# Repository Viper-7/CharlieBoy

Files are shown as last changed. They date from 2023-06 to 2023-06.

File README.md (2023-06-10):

# CharlieBoy

A hand-held gaming console / Arduino experimenters kit.

A1CyZcg

Just yesterday I learned I have a nephew who is turning 11 next week, with interests in computers, gaming, and art. This was my 24 hour project to make a gift for him, as a toy and hopefully a gateway into the wide world of electronics.

As it comes it's a Tetris game, simple but surprisingly addictive, I caught myself getting carried away playing it more than a few times while testing 😁 The code for it is in this repository. The LCD is an older ILI9328 shield I had lying around, and I couldn't find many finished game projects for it, so I ported this one from https://github.com/vilaca/Handheld-Color-Console/tree/master/ArduinoTetris



However the real trick is the fact that the unit itself is only held together by the pins on the shield - you can literally just rip the thing apart and start hacking. Once the cover is off there's an Arduino Uno, fully available and ready for breadboarding, with a lithium battery and charger hidden beneath it, and a touchscreen, joystick with button, and power switch for user interface.

C0damcI

It's intended to be a platform to start learning electronics and microcontroller development. It's fully customizable, the game on it can be changed or replaced, they can add buttons, dials, lights, etc to it, use the Touchscreen and SD card reader to show photos or art, etc, etc.

The Arduino and Joystick are bolted down, with brass inserts melted into the 3d print. The switch is held in with a screw on collar, and the LCD (both the shield on the inside and the display on the outside) are attached with VHB tape.



Hiding under the Arduino is a TP4056 + DW01 lithium charger + protection module, and a small 500mAh 1S LiPo battery, along with a diode and 2A PTC fuse so any mishaps are a little less dramatic. The joystick is wired to A6 and A7, which are not available on most Arduino Uno boards, but were broken out on this board so I used those to avoid occupying any "regular" pins. With the screen removed, only the switch inside the joystick shares with a regular arduino pin, A5.



Total parts cost was under $20, although shipping may vary. I've included the OpenSCAD files for the chassis, and a list of everything else used in aliexpress links down below



Complete Parts List:

* LCD Module: https://s.click.aliexpress.com/e/_DnsErhJ
* Arduino Uno with A6+A7: https://s.click.aliexpress.com/e/_DmORDdP
* TP4056+DW01: https://s.click.aliexpress.com/e/_DeaHOff
* Joystick Module: https://s.click.aliexpress.com/e/_Dd41Vq1
* Switch + Cover: https://s.click.aliexpress.com/e/_DmSk5vR
* M2 Threaded Inserts: https://s.click.aliexpress.com/e/_DDOrytL
* M2 Bolts: https://s.click.aliexpress.com/e/_DEwoBIp
* 500mAh Battery: https://s.click.aliexpress.com/e/_DCwWl85

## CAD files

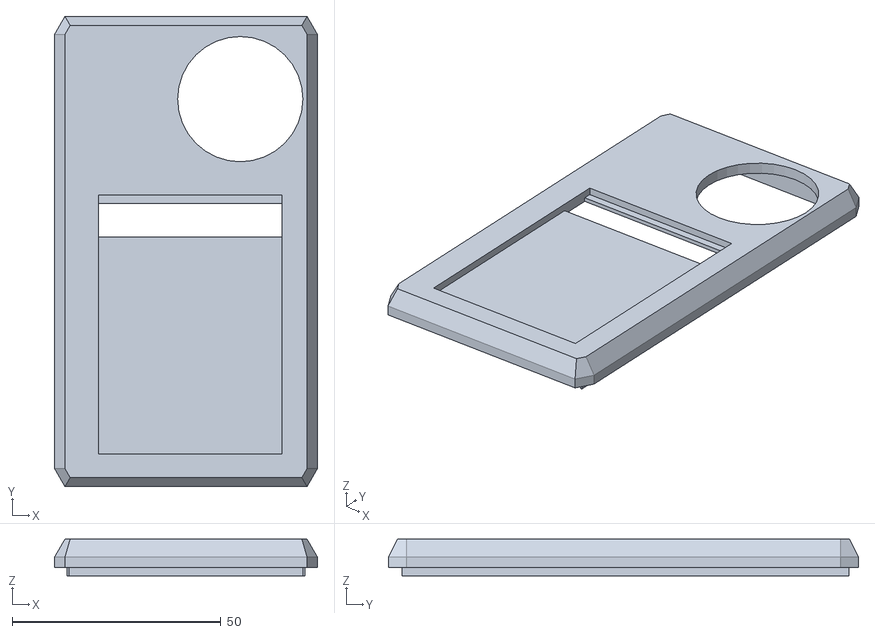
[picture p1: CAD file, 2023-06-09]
CharlieBoy_Lid.stl
63.0 x 112.7 x 8.83

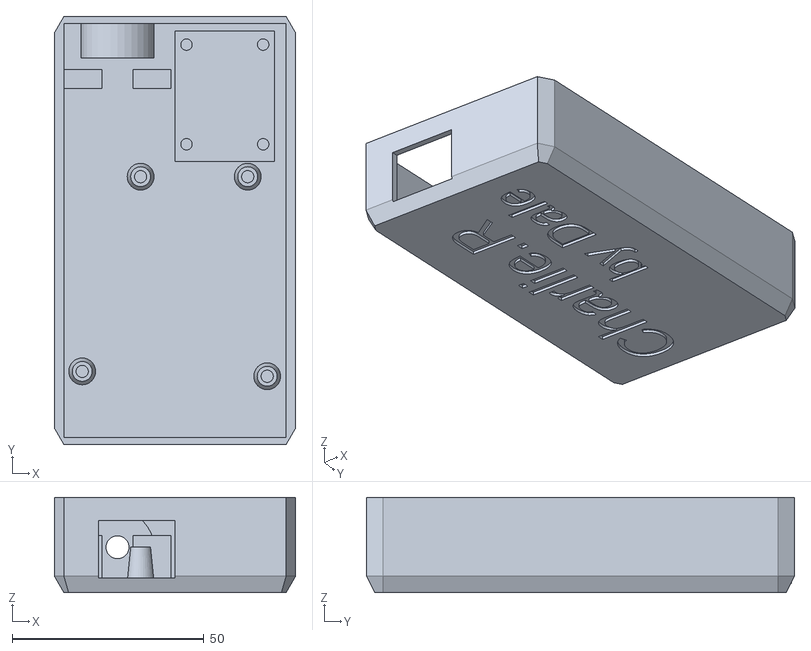
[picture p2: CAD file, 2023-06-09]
CharlieBoy_base.stl
63.0 x 111.7 x 24.8

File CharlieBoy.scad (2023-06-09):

$fn=32;

translate([60,0,25]) rotate([180,0,180]) lid();
//base();

module base() {

 difference() {
    $rad = 5;
    
    color("orange") minkowski() {
        translate([1+$rad/2,1+$rad/2,$rad/2]) cube([58-$rad, 108-$rad,30]);
        sphere($rad, $fn=6);
    }
    translate([1,1,1]) cube([58,108,35]);
    translate([-5,-5,23]) cube([70,150,50]);
    //translate([10,-5,10]) cube([45,10,15]);
    translate([10,-5,2]) cube([20,10,15]);
    translate([15,103,10]) rotate([0,90,90]) cylinder(20, 7.5, 7.5);
    color("gray") rotate([0,180,0]) translate([-28,103,1]) rotate([0,0,270]) linear_extrude(5) text("Charlie.R", size=15);
    color("gray") rotate([0,180,0]) translate([-46,65,1]) rotate([0,0,270]) linear_extrude(5) text("by Dale", size=12);
}

translate([3.25,3,0]) union() {
    //translate([0,0,10]) arduino();
    standoffs();
}

translate([1,92,0]) cube([10,5,13]);
translate([19,92,0]) cube([10,5,13]);

difference() {
    translate([15,100,10]) rotate([0,90,90]) cylinder(10, 9.5, 9.5);
    
    translate([15,103,10]) rotate([0,90,90]) cylinder(20, 7.5, 7.5);
    translate([15,90,10]) rotate([0,90,90]) cylinder(50, 3, 3);
}

//translate([30,75,20])  color("darkgray",1) joystick();
translate([30,73,1]) difference() {
    cube([26,34,12]);
    translate([0,0,2]) joystickHoles();
}
}

module lid() {
color("gray") difference() {
    $rad = 5;
    
    minkowski() {
        translate([1+$rad/2,+$rad/2,$rad/2]) cube([58-$rad, 109-$rad,30]);
        sphere($rad, $fn=6);
    }
    translate([1,0,1]) cube([58,108,35]);
    translate([-5,-5,5]) cube([70,150,50]);
    translate([7,58,-7]) cube([44,8,30]);
    translate([7,6,-5]) cube([44,62,5]);
    translate([17,89,-10]) cylinder(18,15,15);
}

//translate([9,6,-5]) color("white") cube([42,60,5]);
//translate([10,7,-5.1]) color("black") cube([40,58,2]);

difference() {
    union() {
        translate([1,2,1]) cube([58,107,4]);
        translate([1.5,1.5,1]) cube([57,107,6]);
    }
    translate([2,0,1]) cube([56,108,16]);
    translate([7,58,-7]) cube([44,8,30]);
    translate([17,89,-10]) cylinder(18,15,15);
}
}

module joystickHoles() {
    translate([3,4.5,0]) union() {
        translate([0,0,0]) cylinder(50, 1.5, 1.5);
        translate([20,0,0]) cylinder(50, 1.5, 1.5);
        translate([0,26,0]) cylinder(50, 1.5, 1.5);
        translate([20,26,0]) cylinder(50, 1.5, 1.5);
    }
}
    
module joystick() {
    difference() {
        cube([26,34,6]);
        joystickHoles();
    }
    translate([13,17,6]) cylinder(16,6,6);
    translate([13,17,14]) intersection() { sphere(12); cylinder(10,13,13); }
}


// Arduino connectors library
//
// Copyright (c) 2013 Kelly Egan
//
// The MIT License (MIT)
//
// Permission is hereby granted, free of charge, to any person obtaining a copy of this software 
// and associated documentation files (the "Software"), to deal in the Software without restriction, 
// including without limitation the rights to use, copy, modify, merge, publish, distribute, sublicense,
// and/or sell copies of the Software, and to permit persons to whom the Software is furnished to do 
// so, subject to the following conditions:
//
// The above copyright notice and this permission notice shall be included in all copies or substantial
// portions of the Software.
//
// THE SOFTWARE IS PROVIDED "AS IS", WITHOUT WARRANTY OF ANY KIND, EXPRESS OR IMPLIED, INCLUDING BUT 
// NOT LIMITED TO THE WARRANTIES OF MERCHANTABILITY, FITNESS FOR A PARTICULAR PURPOSE AND NONINFRINGEMENT. 
// IN NO EVENT SHALL THE AUTHORS OR COPYRIGHT HOLDERS BE LIABLE FOR ANY CLAIM, DAMAGES OR OTHER LIABILITY,
// WHETHER IN AN ACTION OF CONTRACT, TORT OR OTHERWISE, ARISING FROM, OUT OF OR IN CONNECTION WITH THE 
// SOFTWARE OR THE USE OR OTHER DEALINGS IN THE SOFTWARE.
//

use <pin_connectors/pins.scad>

//Constructs a roughed out arduino board
//Current only USB, power and headers
module arduino(boardType = UNO) {
  //The PCB with holes
  difference() {
    color("SteelBlue") 
      boardShape( boardType );
    translate([0,0,-pcbHeight * 0.5]) holePlacement(boardType = boardType)
      color("SteelBlue") cylinder(r = mountingHoleRadius, h = pcbHeight * 2, $fn=32);
  }
  //Add all components to board
  components( boardType = boardType, component = ALL );
}

//Creates a bumper style enclosure that fits tightly around the edge of the PCB.
module bumper( boardType = UNO, mountingHoles = false ) {
  bumperBaseHeight = 2;
  bumperHeight = bumperBaseHeight + pcbHeight + 0.5;
  dimensions = boardDimensions(boardType);

  difference() {
    union() {
      //Outer rim of bumper
      difference() {
        boardShape(boardType = boardType, offset=1.4, height = bumperHeight);
        translate([0,0,-0.1])
          boardShape(boardType = boardType, height = bumperHeight + 0.2);
      }

      //Base of bumper  
      difference() {
        boardShape(boardType = boardType, offset=1, height = bumperBaseHeight);
        translate([0,0, -0.1])
          boardShape(boardType = boardType, offset=-2, height = bumperHeight + 0.2);
      }

      //Board mounting holes
      holePlacement(boardType=boardType)
        cylinder(r = mountingHoleRadius + 1.5, h = bumperBaseHeight, $fn = 32);

      //Bumper mounting holes (exterior)
      if( mountingHoles ) {
        difference() {  
          hull() {
            translate([-6, (dimensions[1] - 6) / 2, 0])
              cylinder( r = 6, h = pcbHeight + 2, $fn = 32 );
            translate([ -0.5, dimensions[1] / 2 - 9, 0])
              cube([0.5, 12, bumperHeight]);
          }
          translate([-6, (dimensions[1] - 6) / 2, 0])
            mountingHole(holeDepth = bumperHeight);
        }
        difference() {  
          hull() {
            translate([dimensions[0] + 6, (dimensions[1] - 6) / 2,0])
              cylinder( r = 6, h = pcbHeight + 2, $fn = 32 );
            translate([ dimensions[0], dimensions[1] / 2 - 9, 0]) 
              cube([0.5, 12, bumperHeight]);
          }
          translate([dimensions[0] + 6, (dimensions[1] - 6) / 2,0])
            mountingHole(holeDepth = bumperHeight);
        }
      }
    }
    translate([0,0,-0.5])
    holePlacement(boardType=boardType)
      cylinder(r = mountingHoleRadius, h = bumperHeight, $fn = 32);  
    translate([0, 0, bumperBaseHeight]) {
      components(boardType = boardType, component = ALL, offset = 1);
    }
    translate([4,(dimensions[1] - dimensions[1] * 0.4)/2,-1])
      cube([dimensions[0] -8,dimensions[1] * 0.4,bumperBaseHeight + 2]);
  }
}

//Setting for enclosure mounting holes (Not Arduino mounting)
NOMOUNTINGHOLES = 0;
INTERIORMOUNTINGHOLES = 1;
EXTERIORMOUNTINGHOLES = 2;

//Create a board enclosure
module enclosure(boardType = UNO, wall = 3, offset = 3, heightExtension = 10, cornerRadius = 3, mountType = TAPHOLE) {
  standOffHeight = 5;

  dimensions = boardDimensions(boardType);
  boardDim = boardDimensions(boardType);
  pcbDim = pcbDimensions(boardType);

  enclosureWidth = pcbDim[0] + (wall + offset) * 2;
  enclosureDepth = pcbDim[1] + (wall + offset) * 2;
  enclosureHeight = boardDim[2] + wall + standOffHeight + heightExtension;

  union() {
    difference() {
      //Main box shape
      boundingBox(boardType = boardType, height = enclosureHeight, offset = wall + offset, include=PCB, cornerRadius = wall);
  
      translate([ 0, 0, wall]) {
        //Interior of box
        boundingBox(boardType = boardType, height = enclosureHeight, offset = offset, include=PCB, cornerRadius = wall);
  
        //Punch outs for USB and POWER
        translate([0, 0, standOffHeight]) {
          components(boardType = boardType, offset = 1, extension = wall + offset + 10);
        }
      }
      
      //Holes for lid clips
      translate([0, enclosureDepth * 0.75 - (offset + wall), enclosureHeight]) {
        translate([-offset, 0, 0])
          rotate([0, 180, 90]) clipHole(clipHeight = 10, holeDepth = wall + 0.2);
        translate([offset + boardDim[0], 0, 0])
          rotate([0, 180, 270]) clipHole(clipHeight = 10, holeDepth = wall + 0.2);
      }
    
      translate([0, enclosureDepth * 0.25 - (offset + wall), enclosureHeight]) {
        translate([-offset, 0, 0])
          rotate([0, 180, 90]) clipHole(clipHeight = 10, holeDepth = wall + 0.2);
        translate([offset + dimensions[0], 0, 0])
          rotate([0, 180, 270]) clipHole(clipHeight = 10, holeDepth = wall + 0.2);
      }   
    }
    translate([0, 0, wall]) {
      standoffs(boardType = boardType, height = standOffHeight, mountType = mountType);
    }
  }
}

//Create a snap on lid for enclosure
module enclosureLid( boardType = UNO, wall = 3, offset = 3, cornerRadius = 3, ventHoles = false) {
  dimensions = boardDimensions(boardType);
  boardDim = boardDimensions(boardType);
  pcbDim = pcbDimensions(boardType);

  enclosureWidth = pcbDim[0] + (wall + offset) * 2;
  enclosureDepth = pcbDim[1] + (wall + offset) * 2;
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

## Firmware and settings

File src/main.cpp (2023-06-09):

#include <Arduino.h>

// Simple Drawing Script for AZ-Delivery TFT Touch 240x320 Shield
// Tony Goodhew 30 Sept 2020
// Modified from Adafruit examples for a similar shield
// Tutorial45.com
// Adafruit GFX Libraries
#include <Adafruit_GFX.h>
#include <Adafruit_TFTLCD.h>
#include <Fonts/FreeSans18pt7b.h>
#include <Fonts/FreeMono9pt7b.h>

#include "joystick.cpp"
#include "beeping.cpp"
//#include "sequencer.cpp"


#define LCD_CS A3     // Chip Select goes to Analog 3
#define LCD_CD A2     // Command/Data goes to Analog 2
#define LCD_WR A1     // LCD Write goes to Analog 1
#define LCD_RD A0     // LCD Read goes to Analog 0
#define LCD_RESET A4  // Can alternately just connect to Arduino's reset pin

// 16-bit colour values:
#define BLACK 0xFFFF
#define BLUE 0x001F
#define RED 0xF800
#define GREEN 0x07E0
#define CYAN 0x07FF
#define MAGENTA 0xF81F
#define YELLOW 0xFFE0
#define ORANGE 0xF87F
#define WHITE 0x0000
#define GRAY2 0xF7EF
unsigned int c[] = {BLACK,RED,GREEN,BLUE,CYAN,MAGENTA,YELLOW,WHITE};
int cc = c[1];

// Create the TFT (Graphics) object - named pins
Adafruit_TFTLCD tft(LCD_CS, LCD_CD, LCD_WR, LCD_RD, LCD_RESET);



#define LCD_WIDTH             319
#define LCD_HEIGHT            239

#define MIN(X, Y)             (((X) < (Y)) ? (X) : (Y))

#define BOARD_WIDTH           11
#define BOARD_HEIGHT          20

#define BLOCK_SIZE            MIN( (LCD_WIDTH-1) / BOARD_WIDTH, (LCD_HEIGHT-1) / BOARD_HEIGHT )

#define BOARD_LEFT            118//(LCD_WIDTH - BOARD_WIDTH * BLOCK_SIZE)/3*4
#define BOARD_RIGHT           (BOARD_LEFT + BLOCK_SIZE * BOARD_WIDTH)
#define BOARD_TOP             80//(LCD_HEIGHT - BOARD_HEIGHT * BLOCK_SIZE) / 2
#define BOARD_BOTTOM          (BOARD_TOP + BOARD_HEIGHT * BLOCK_SIZE)

#define PIT_COLOR             GREEN
#define BG_COLOR              BLACK

#define DROP_WAIT_INIT        1100

#define INPUT_WAIT_ROT        300
#define INPUT_WAIT_MOVE       150

#define INPUT_WAIT_NEW_SHAPE  400

// used to clear the position from the screen
typedef struct Backup {
  byte x, y, rot;
};


class Tetris
{
  // shapes definitions
  
  byte l_shape[4][4][2] {
    {{0, 0}, {0, 1}, {0, 2}, {1, 2}},
    {{0, 1}, {1, 1}, {2, 0}, {2, 1}},
    {{0, 0}, {1, 0}, {1, 1}, {1, 2}},
    {{0, 0}, {0, 1}, {1, 0}, {2, 0}},
  };

  byte j_shape[4][4][2] {
    {{1, 0}, {1, 1}, {0, 2}, {1, 2}},
    {{0, 0}, {1, 0}, {2, 0}, {2, 1}},
    {{0, 0}, {1, 0}, {0, 1}, {0, 2}},
    {{0, 0}, {0, 1}, {1, 1}, {2, 1}},
  };

  byte o_shape[1][4][2] {
    { {0, 0}, {0, 1}, {1, 0}, {1, 1}}
  };

  byte s_shape[2][4][2] {
    {{0, 1}, {1, 0}, {1, 1}, {2, 0}},
    {{0, 0}, {0, 1}, {1, 1}, {1, 2}}
  };

  byte z_shape[2][4][2] {
    {{0, 0}, {1, 0}, {1, 1}, {2, 1}},
    {{1, 0}, {0, 1}, {1, 1}, {0, 2}}
  };

  byte t_shape[4][4][2] {
    {{0, 0}, {1, 0}, {2, 0}, {1, 1}},
    {{0, 0}, {0, 1}, {1, 1}, {0, 2}},
    {{1, 0}, {0, 1}, {1, 1}, {2, 1}},
    {{1, 0}, {0, 1}, {1, 1}, {1, 2}}
  };

  byte i_shape[2][4][2] {
    {{0, 0}, {1, 0}, {2, 0}, {3, 0}},
    {{0, 0}, {0, 1}, {0, 2}, {0, 3}}
  };

  // All game shapes and their colors

  byte *all_shapes[7] = {l_shape[0][0], j_shape[0][0], o_shape[0][0], s_shape[0][0], z_shape[0][0], t_shape[0][0], i_shape[0][0]};

  unsigned int colors[7] = {ORANGE, BLUE, YELLOW, GREEN, RED, MAGENTA, CYAN};


  // how many rotated variations each shape has
  
  byte shapes[7] = {4, 4, 1, 2, 2, 4, 2};


  // game progress
  
  int lines, level;

  // current shapes
  
  byte current;
  
  // tetris guidelines have all 7 shapes
  // selected in sequence to avoid
  // long runs without a shape
  
  byte next[7];
  byte next_c;

  unsigned long lastInput, lastDrop;

  byte board[BOARD_HEIGHT][BOARD_WIDTH];

  byte x, y, rot;
  Backup old;

  boolean newShape;

  int dropWait;

  public:
  Tetris() : newShape(true), lines(0)
  {
  }

  void run()
  {
    randomSeed(analogRead(2));

    for ( int i = 0; i < BOARD_WIDTH; i++ )
    {
      for ( int j = 0; j < BOARD_HEIGHT; j++)
      {
        board[j][i] = 0;
      }
    }

    //next shape
    
    randomizer();

    // initialize game logic
    
    lastInput = 0;
    lastDrop = 0;
    dropWait = DROP_WAIT_INIT;
    level = 1;

    // draw background
    int c = LCD_WIDTH / 28;
    for (int i = 0; i<=28;i++)
    {
      tft.fillRect(0, i*c, LCD_HEIGHT, c, tft.color565(min((i+5)*12,255),min((i+15)*8,255),i*7));
    }

    tft.fillRect(BOARD_LEFT, BOARD_TOP, BOARD_RIGHT-BOARD_LEFT-1, BOARD_BOTTOM-BOARD_TOP, BG_COLOR);

    // draw board left limit
    
    tft.drawLine (
      BOARD_LEFT - 1,
      BOARD_TOP-1,
      BOARD_RIGHT,
      BOARD_TOP-1,
      PIT_COLOR);

    // draw board left limit
    
    tft.drawLine (
      BOARD_LEFT - 1,
      BOARD_TOP,
      BOARD_LEFT - 1,
      BOARD_BOTTOM,
      PIT_COLOR);

    // draw board right limit
    
    tft.drawLine (
      BOARD_RIGHT,
      BOARD_TOP,
      BOARD_RIGHT,
      BOARD_BOTTOM,
      PIT_COLOR);

    // draw board bottom limit
    
    tft.drawLine (
      BOARD_LEFT - 1,
      BOARD_BOTTOM,
      BOARD_RIGHT + 1,
      BOARD_BOTTOM,
      PIT_COLOR);

    for ( int i = BOARD_LEFT + BLOCK_SIZE - 1; i < BOARD_RIGHT; i += BLOCK_SIZE)
    {
      tft.drawLine (
        i,
        BOARD_TOP,
        i,
        BOARD_BOTTOM - 1,
        GRAY2);
    }

    for ( int i = BOARD_TOP + BLOCK_SIZE - 1; i < BOARD_BOTTOM; i += BLOCK_SIZE)
    {
      tft.drawLine (
        BOARD_LEFT,
        i,
        BOARD_RIGHT - 1,
        i,
        GRAY2);
    }

    scoreBoard();

    do {

      // get clock
      const unsigned long now = millis();

      // display new shape
      if ( newShape )
      {
        Joystick::waitForRelease(INPUT_WAIT_NEW_SHAPE);
        newShape = false;

        // a new shape enters the game
        chooseNewShape();

        // draw next box
        tft.fillRect(30, 100, BLOCK_SIZE * 6, BLOCK_SIZE * 5, BLACK);
        tft.drawRect(29, 99, BLOCK_SIZE * 6 + 1, BLOCK_SIZE * 5 + 1, WHITE);

        byte *shape = all_shapes[next[next_c]];
        for ( int i = 0; i < 4; i++ )
        {
          byte *block = shape + i * 2;
          tft.fillRoundRect(
            30 + BLOCK_SIZE + block[0]*BLOCK_SIZE,
            100 + BLOCK_SIZE + block[1]*BLOCK_SIZE,
            BLOCK_SIZE - 2,
            BLOCK_SIZE - 2 ,
            1,
            colors[next[next_c]]);
        }

        // check if new shape is placed over other shape(s)
        // on the board
        if ( touches(0, 0, 0 ))
        {
          // draw shape to screen
          draw();
          return;
        }

        // draw shape to screen
        draw();
      }
      else
      {
        // check if enough time has passed since last time the shape
        // was moved down the board
        if ( now - lastDrop > dropWait || Joystick::getY() > Joystick::NEUTRAL)
        {
          // update clock
          lastDrop = now;
          moveDown();
          delay(10);
        }
      }

      if (!newShape)
      {
        userInput(now);
      }

    } while (true);
  }

  private:

  void chooseNewShape()
  {
    current = next[next_c];

    next_c++;
    
    if ( next_c == 7 )
    {
      randomizer();
    }

    // new shape must be positioned at the middle of
    // the top of the board
    // with zero rotation
    
    rot = 0;
    y = 0;
    x = BOARD_WIDTH / 2;

    old.rot = rot;
    old.y = y;
    old.x = x;
  }

  void userInput(unsigned long now)
  {
    unsigned long waited = now - lastInput;

    int jx = Joystick::getX();    

    int move = INPUT_WAIT_MOVE / jx;

    if ( jx < Joystick::NEUTRAL && waited > -move)
    {
      if  (x > 0 && !touches(-1, 0, 0))
      {
        x--;
        lastInput = now;
        draw();
      }
    }
    else if ( jx > Joystick::NEUTRAL && waited > move )
    {
      if ( x < BOARD_WIDTH && !touches(1, 0, 0))
      {
        x++;
        lastInput = now;
        draw();
      }
    }
    
    if ( Joystick::fire() )
    {
      while ( !touches(0, 1, 0 ))
      {
        y++;
      }
      lastInput = now;
      draw();
    }

    int my = Joystick::getY();
    if (( my == -Joystick::HARD && waited > INPUT_WAIT_ROT ) || ( my == -Joystick::HARDER && waited > INPUT_WAIT_ROT / 2 ))
    {
      if (Joystick::getY() < 0 && !touches(0, 0, 1))
      {
        rot++;
        rot %= shapes[current];
        lastInput = now;
        draw();
      }
    }
  }

  void moveDown()
  {
    // prepare to move down
    // check if board is clear bellow
    
    if ( touches(0, 1, 0 ))
    {
      // moving down touches another shape
      newShape = true;

      // this shape wont move again
      // add it to the board
      
      byte *shape = all_shapes[current];
      for ( int i = 0; i < 4; i++ )
      {
        byte *block = (shape + (rot * 4 + i) * 2);
        board[block[1] + y][block[0] + x] = current + 1;
      }

      // check if lines were made
      
      score();
      Beeping::beep(1500, 25);
    }
    else
    {
      // move shape down
      y += 1;
      draw();
    }
  }

  void draw()
  {
    byte *shape = all_shapes[current];
    for ( int i = 0; i < 4; i++ )
    {
      byte *block = (shape + (rot * 4 + i) * 2);

      tft.fillRoundRect(
        BOARD_LEFT + block[0]*BLOCK_SIZE + BLOCK_SIZE * x,
        BOARD_TOP + block[1]*BLOCK_SIZE + BLOCK_SIZE * y,
        BLOCK_SIZE - 2,
        BLOCK_SIZE - 2 ,
        1,
        colors[current]);

      board[block[1] + y][block[0] + x] = 255;
    }

    // erase old
    for ( int i = 0; i < 4; i++ )
    {
      byte *block = (shape + (old.rot * 4 + i) * 2);

      if ( board[block[1] + old.y][block[0] + old.x] == 255 )
      continue;

      tft.fillRect(
        BOARD_LEFT + block[0]*BLOCK_SIZE + BLOCK_SIZE * old.x,
        BOARD_TOP + block[1]*BLOCK_SIZE + BLOCK_SIZE * old.y,
        BLOCK_SIZE - 2,
        BLOCK_SIZE - 2 ,
        BG_COLOR);
    }

    for ( int i = 0; i < 4; i++ )
    {
      byte *block = (shape + (rot * 4 + i) * 2);
      board[block[1] + y][block[0] + x] = 0;
    }

    old.x = x;
    old.y = y;
    old.rot = rot;
  }

  boolean touches(int xi, int yi, int roti)
  {
    byte *shape = all_shapes[current];
    for ( int i = 0; i < 4; i++ )
    {
      byte *block = (shape + (((rot + roti) % shapes[current]) * 4 + i) * 2);

      int x2 = x + block[0] + xi;
      int y2 = y + block[1] + yi;

      if ( y2 == BOARD_HEIGHT || x2 == BOARD_WIDTH || board[y2][x2] != 0 )
      {
        return true;
      }
    }
    return false;
  }

  void score()
  {
    // we scan a max of 4 lines
    int ll;
    if ( y + 3 >= BOARD_HEIGHT )
    {
      ll = BOARD_HEIGHT - 1;
    }

    // scan board from current position
    for (int l = y; l <= ll; l++)
    {
      // check if there's a complete line on the board
      boolean line = true;

      for ( int c = 0; c < BOARD_WIDTH; c++ )
      {
        if (board[l][c] == 0)
        {
          line = false;
          break;
        }
      }

      if ( !line )
      {
        // move to next line
        continue;
      }

      Beeping::beep(3000, 50);

      lines++;

      if ( lines % 10 == 0 )
      {
        level++;
        dropWait /= 2;
      }

      scoreBoard();

      // move board down
      for ( int row = l; row > 0; row -- )
      {
        for ( int c = 0; c < BOARD_WIDTH; c++ )
        {
          byte v = board[row - 1][c];

          board[row][c] = v;
          tft.fillRoundRect(
            BOARD_LEFT + BLOCK_SIZE * c,
            BOARD_TOP + BLOCK_SIZE * row,
            BLOCK_SIZE - 2,
            BLOCK_SIZE - 2 ,
            1,
            v == 0 ? BLACK : colors[v - 1] ) ;
        }
      }

      // clear top line
      for ( int c = 0; c < BOARD_WIDTH; c++ )
      {
        board[0][c] = 0;
      }

/*      tft.fillRect(
        BOARD_LEFT,
        BOARD_TOP,
        BOARD_RIGHT - BOARD_LEFT,
        BLOCK_SIZE,
        BLACK ) ;*/
    }

    delay(350);
  }

  void scoreBoard()
  {
    tft.fillRect(6, 3, 128, 50, BLACK);
    tft.setFont(&FreeMono9pt7b);
    tft.setTextColor(YELLOW);
    tft.setCursor(20, 20);
    tft.print("Level");
    tft.setCursor(20, 40);
    tft.print("Lines");
    tft.setCursor(100, 20);
    tft.print(level);
    tft.setCursor(100, 40);
    tft.print(lines);
    tft.drawRect(5, 2, 130, 52, GREEN);
  }

  // create a sequence of 7 random shapes
  
  void randomizer()
  {
    // randomize 7 shapes
    
    for ( byte i = 0; i < 7; i ++)
    {
      boolean retry;
      byte shape;
      do
      {
        shape = random(7);
        
        // check if already in sequence
        
        retry= false;
        for ( int j = 0; j < i; j++)
        {
          if ( shape == next[j] )
          {
            retry = true;
            break;
          }
        }

      } while (retry);
      next[i] = shape;
    }
    next_c = 0;
  }  
};

void drawPreGameScreen()
{
  tft.fillScreen(BLACK);
  tft.setTextColor(BLUE);
  tft.setCursor(70,140);
  tft.println("Tetris");
  tft.setCursor(30,210);
  tft.println("Click to play");
  //tft.setCursor(50,250);
  //tft.println("Charlie.R");
}

void gameOver()
{
  tft.fillRect(16, 84, 200, 52, BLACK);
  tft.setFont(&FreeSans18pt7b);
  tft.setCursor(27,120);
  tft.setTextColor(WHITE);
  tft.print("Game Over");
  tft.drawRect(16, 84, 200, 52, CYAN);

delay(300);
/*  Beeping::beep(600, 200);
  delay(300);
  Beeping::beep(600, 200);
  delay(300);
  Beeping::beep(200, 600);
  delay(1500);*/
  Joystick::waitForClick();
}


//ISR(TIMER1_COMPA_vect) {

  // sequencer plays tetris theme
  //Sequencer::play();
//}

void setup() {

  //Sequencer::init();

  //TFT_BL_ON;      // turn on the background light

//  tft.init();  // init TFT library
  tft.reset();
  tft.begin(0x9341);  // SDFP5408
  tft.setRotation(2);
  tft.setFont(&FreeSans18pt7b);
  // play turnon sound	
  Beeping::turnOn();

  // initialize joystick
  Joystick::init();
}

void loop() {

  // title screen
  drawPreGameScreen();

  // wait a bit before playing sounds
  //delay(700);

  // start playing tetris theme
  //Sequencer::start();

  // wait for click
  while (!Joystick::fire());

  // stop playing tetris theme
  //Sequencer::stop();

  // load game
  Tetris t;
  t.run();

  // game ended
  gameOver();
}
